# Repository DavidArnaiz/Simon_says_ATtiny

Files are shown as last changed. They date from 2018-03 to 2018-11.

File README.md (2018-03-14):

# Simon_says_ATtiny

Simon game on ATtiny45/85 microcontroller

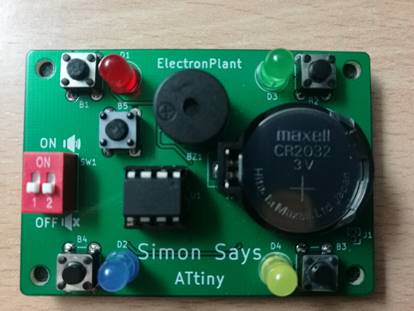
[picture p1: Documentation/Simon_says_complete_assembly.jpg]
Simon_says_ATtiny


Simon_says_ATtiny is a simple project implementing the Simon game on a PCB controlled from a ATtiny45/85. 
The ATtiny is programed from the Arduino IDE.

Repository contents:
--------------------

 +) Documentation: BOM file, Technical specification, drawings...
 
 +) Hardware: Kicad project files, schematic in PDF and Gerber files
 
 +) Firmware: Arduino code.

Game description:
-----------------
Simon (Simon says) game is an electronic game created by Ralph H. Baer and Howard J. Morrison and it has been available since 1970. The game has four lights (typically red, green, yellow and blue) and four buttons. Each light has one button and one sound, generally a tone, linked to it. The game has two main phases:

  +) Sequence display: during this phase “Simon”, the game, will show the sequence you have to memorize. The sequence is shown by turning the lights one at a time until the sequence is completed. Throughout this phase the corresponding tones linked to the lights will also be played to serve as a memory aid.
  
  +) Copying phase: in this phase the player has to copy the sequence in the same order as displayed previously. To copy the sequence the player has to press the corresponding button linked to the light or tone it needs to copy. If there is a mistake while completing the sequence the game will end at that point.
  
These two sequences are repeated over and over increasing the sequence length until either the player louses or the maximum length sequence is reached. The game starts with a sequence of only length one and its length is increased adding one extra step to the current sequence.

Acknowledgments
----------------

For this project to work I'm using the Arduino core created by SpenceKonde:

https://github.com/SpenceKonde/ATTinyCore

Arduino community (Arduino IDE available there):

https://www.arduino.cc/

[The rest of attributions will be on the technical specification document]

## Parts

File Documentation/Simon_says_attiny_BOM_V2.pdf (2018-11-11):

## Simon Says ATtiny BOM

Project Name: | Simon Says Attiny
Designer: | ElectronPlant
Revision: | Rev 1
Date Issue: | 26/01/2018
Reference | Value | Installed | Comment | Quantity

Farnell
code | Digikey code
ATTINY45-20PU U1 | Yes | Attiny45/85 | 1 1288352 | ATTINY45-20PU-ND
NA DIP8 socket | Yes | DIP 8 Socket 1 2668408 | | AE9986-ND
BZ1 Buzzer | Yes | 16 ohm 2k buzzer 1 | 1191946 | 433-1020-ND
SW1 SW_DIP_x02 | Yes | dip swtich 2 bits 1 9472126 | | CT2062ST-ND
J1 AA_Battery | No | | 0
J2 Cell_Battery | Yes | 3V battery holder 20mm | 1 1339839 | | BS-7-ND
B1, B2, B3, B4, B5 SW_Push | Yes | 6mm push botton | 5 | 1960936 | 450-1650-ND
D1 RED_LED | Yes | 5 mm LED (diffuse light) | 1 1581135 | | 754-1264-ND
D3 GREEN_LED | Yes | 5 mm LED (diffuse light) | 1 | 1581138 | 67-1099-ND
D4 YELLOW_LED | Yes | 5 mm LED (diffuse light) | 1 | 1581219 | 754-1284-ND
D2 BLUE_LED | Yes | 5 mm LED (diffuse light) /ORANGE | 1 | 1581141 | 732-5015-ND
C1 22nF | No | SMD 0805 | 1 | 8820104 | 490-1628-2-ND
C2 0.1uF | Yes | SMD 0805 | 1 | 1759143 | 399-1168-1-ND
R1, R5, R6, R7, R9 10k | Yes | SMD 0805 1% tolerance | 5 | 2502671 | 311-10.0KCRCT-ND
R2 20k | Yes | SMD 0805 1% tolerance | 1 | 2073683 | RNCP0805FTD20K0CT-ND
R3 30k | Yes | SMD 0805 1% tolerance | 1 | 2502713 | 311-30.0KCRCT-ND
R4 51k | Yes | SMD 0805 | 1 | 2671056 | 311-51.0KCRCT-ND
R8 100R | Yes | SMD 0805 | 1 | 9333703 | P100DACT-ND
R10, R11, R12, R13 47R | Yes | SMD 0805 | 4 | 2502729 | RHM47KCT-ND

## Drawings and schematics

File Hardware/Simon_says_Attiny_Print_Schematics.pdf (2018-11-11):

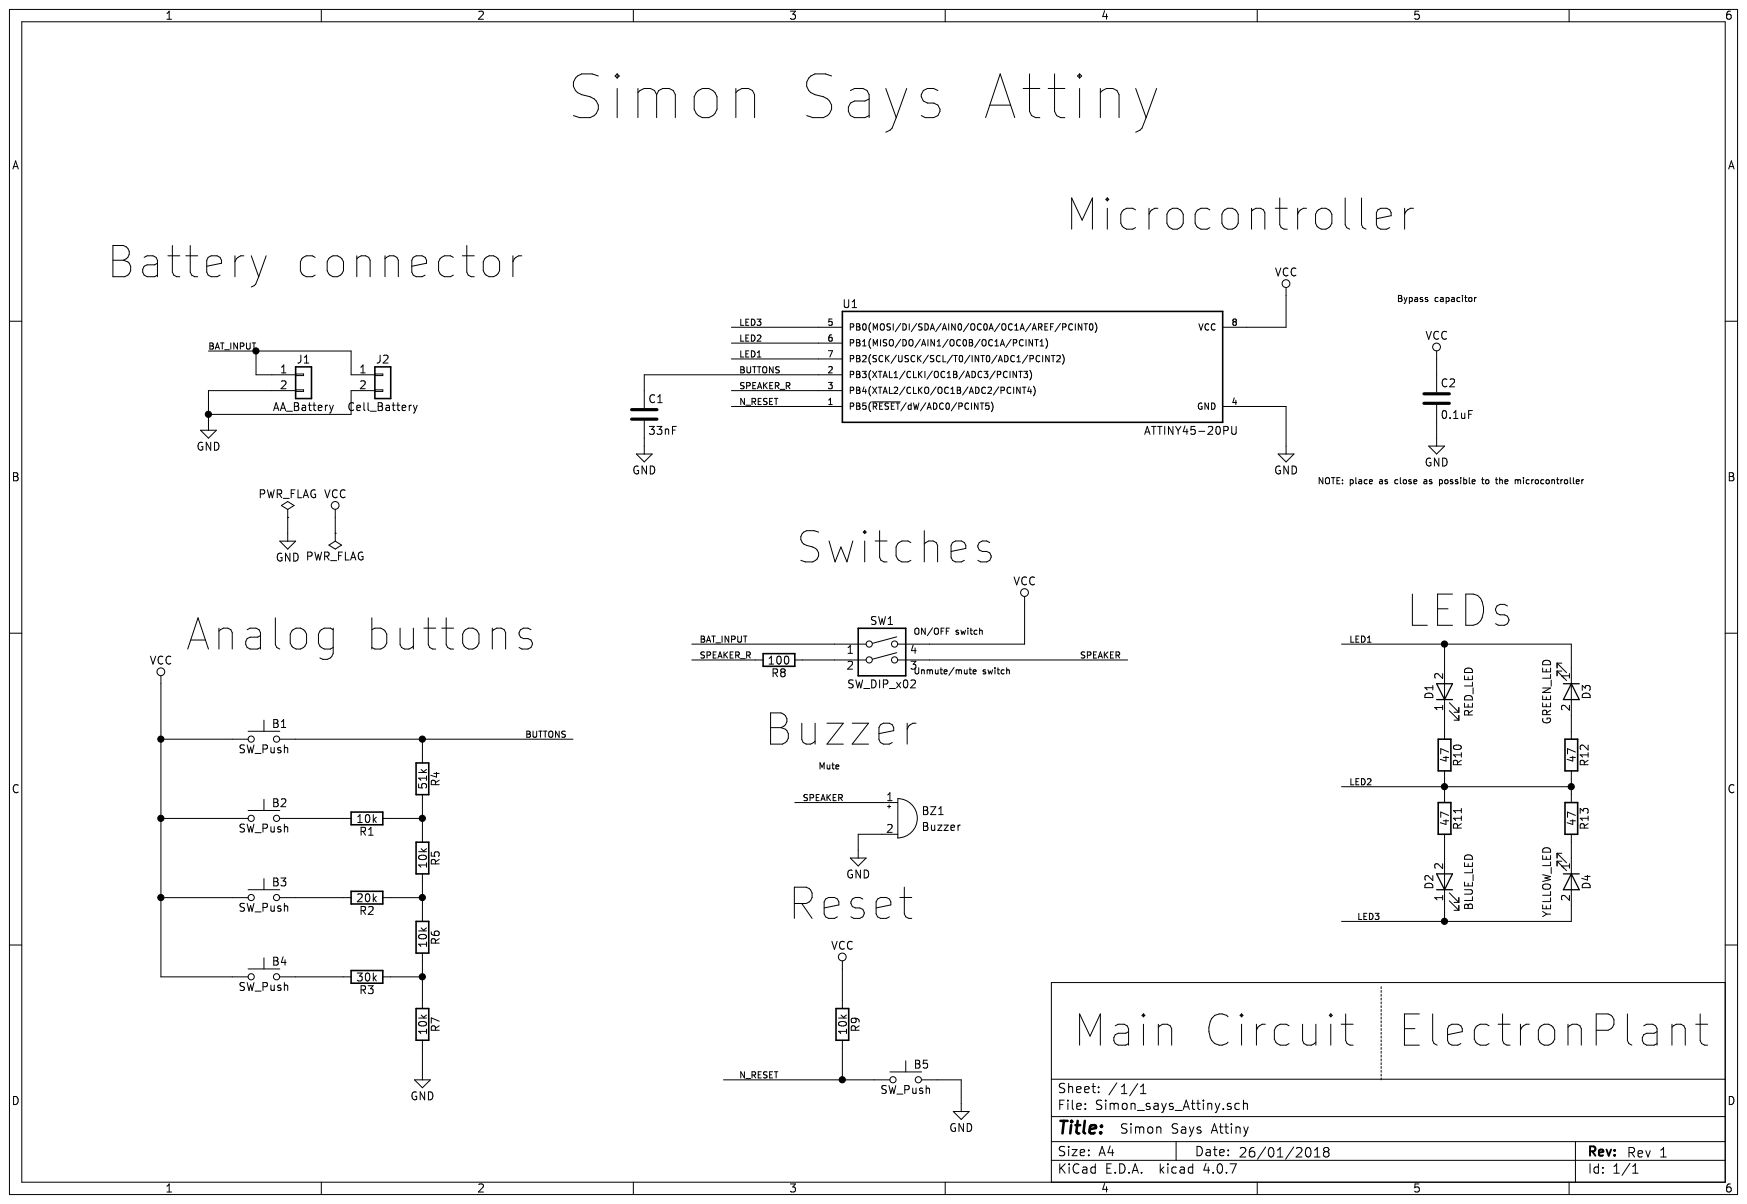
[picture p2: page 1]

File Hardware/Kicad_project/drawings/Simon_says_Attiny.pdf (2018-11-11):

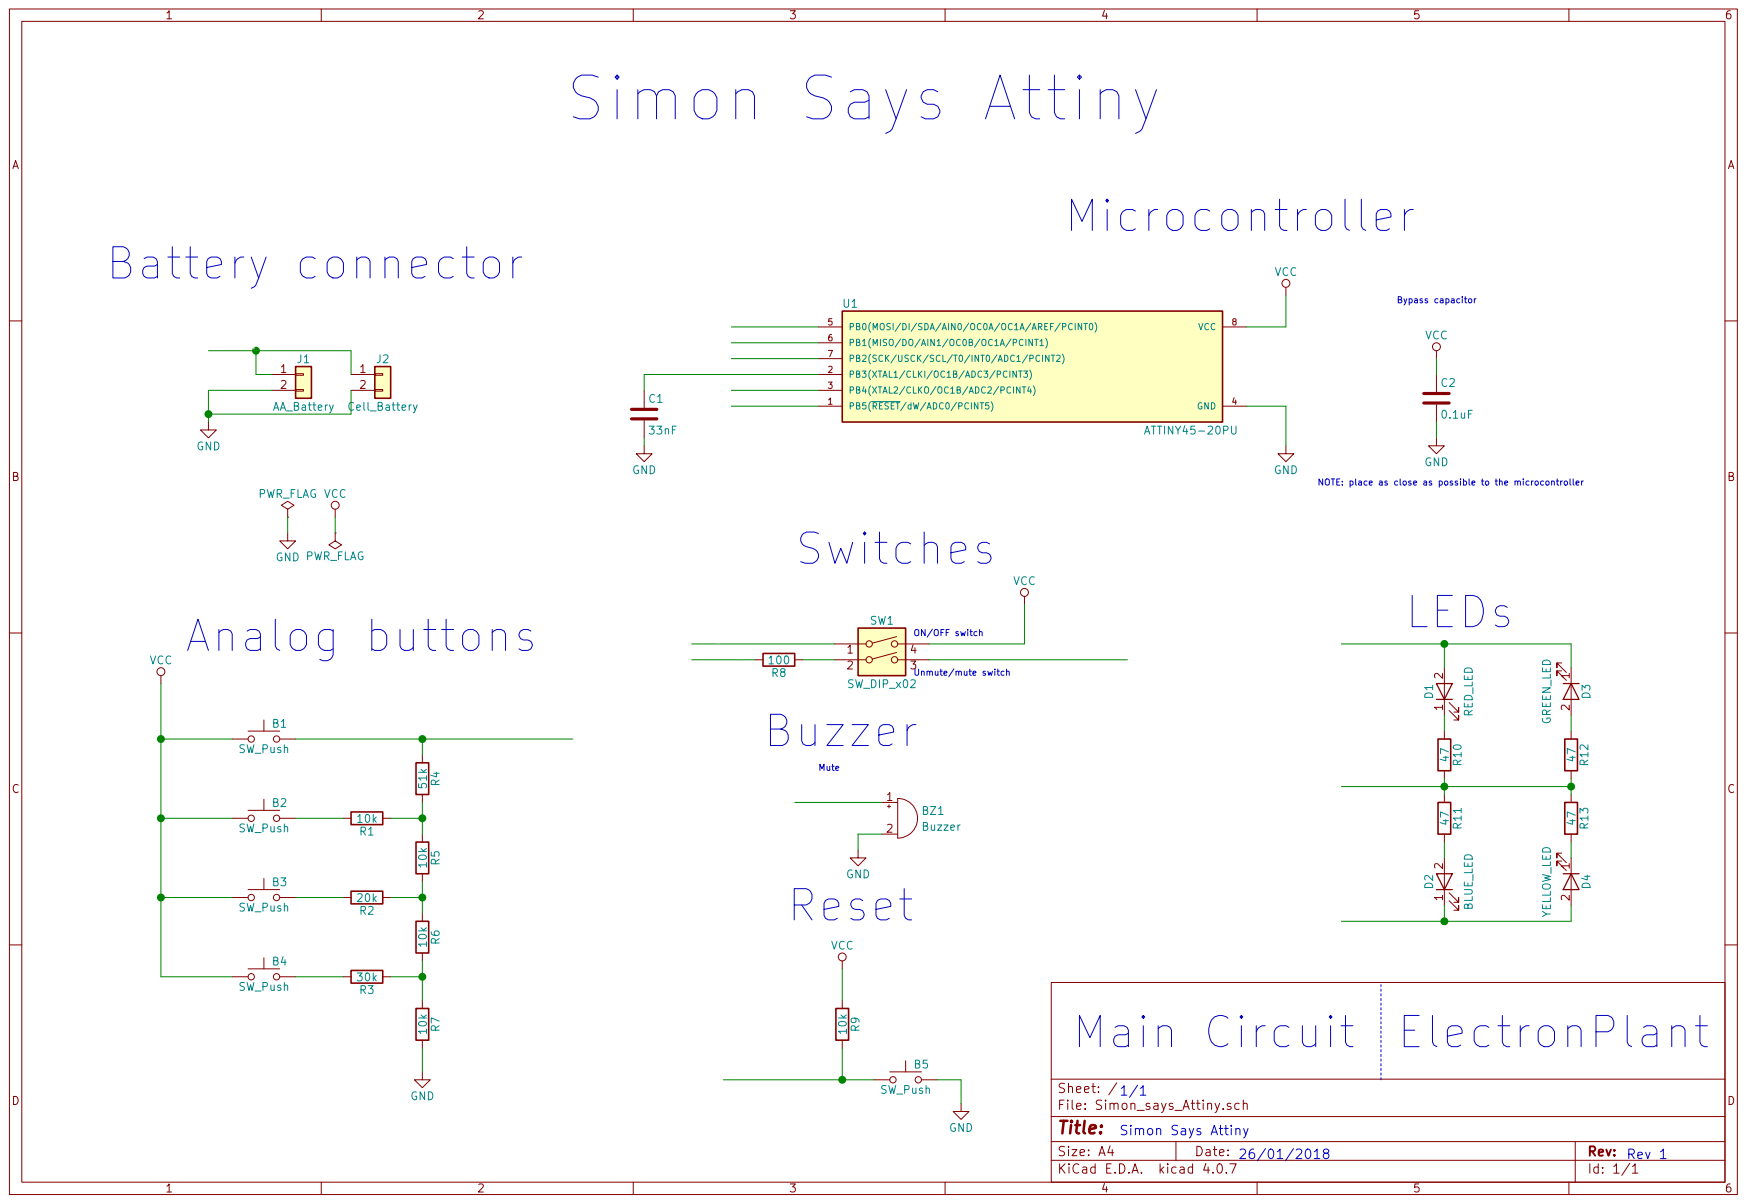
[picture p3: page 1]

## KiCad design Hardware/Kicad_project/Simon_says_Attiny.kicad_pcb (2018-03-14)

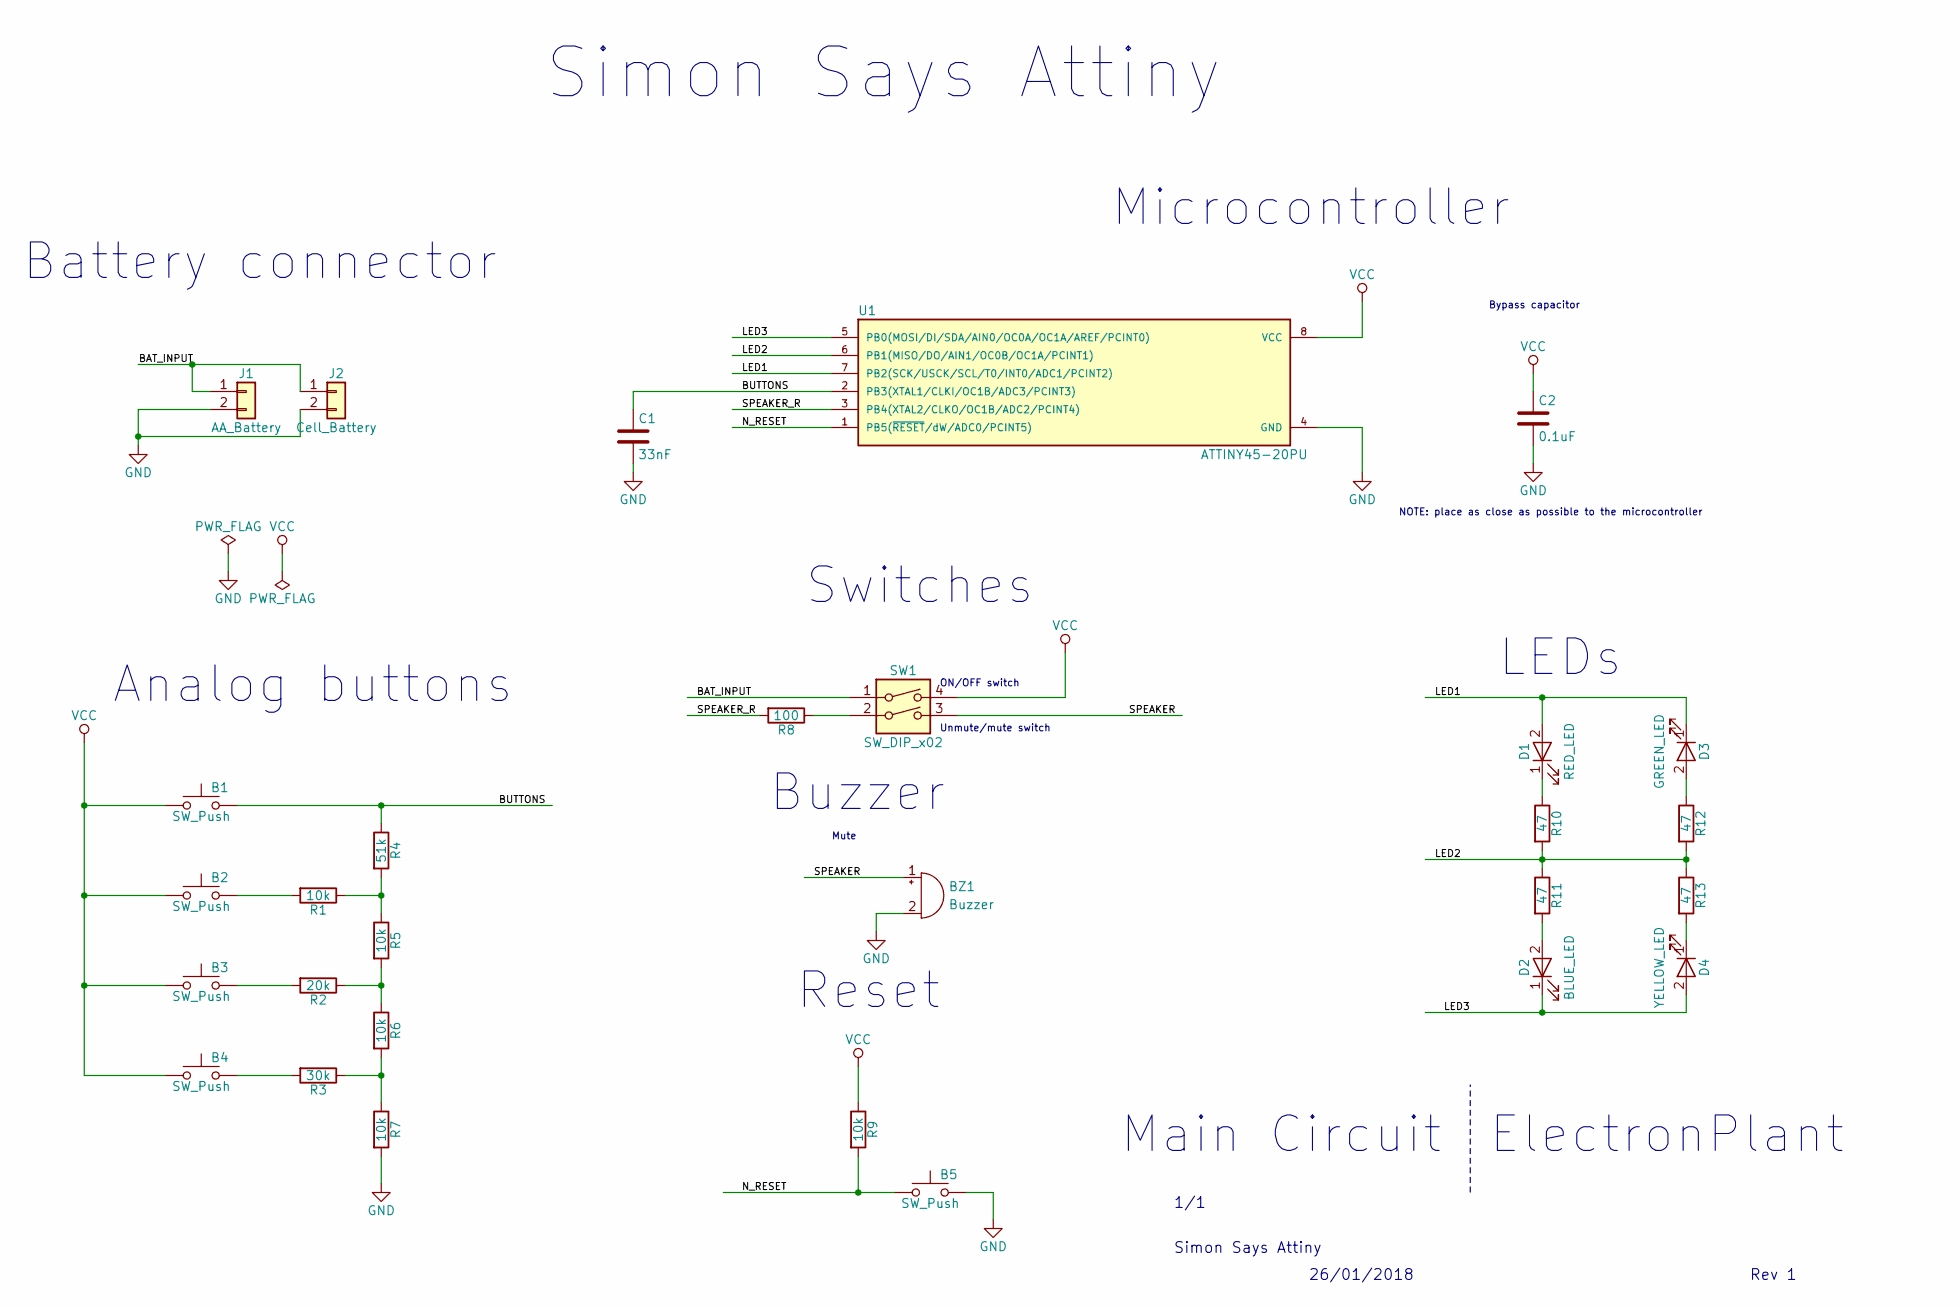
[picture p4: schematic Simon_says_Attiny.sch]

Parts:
B1, B2, B3, B4, B5: SW_Push; SW_PUSH_6mm
BZ1: Buzzer; Buzzer_12x9.5RM7.6
C1: 33nF; C_0805_HandSoldering
C2: 0.1uF; C_0805_HandSoldering
D1: RED_LED; LED_D5.0mm
D2: BLUE_LED; LED_D5.0mm
D3: GREEN_LED; LED_D5.0mm
D4: YELLOW_LED; LED_D5.0mm
J1: AA_Battery; Pin_Header_Straight_1x02_Pitch1.27mm
J2: Cell_Battery; Keystone_103_1x20mm-CoinCell
R1, R5, R6, R7, R9: 10k; R_0805_HandSoldering
R2: 20k; R_0805_HandSoldering
R3: 30k; R_0805_HandSoldering
R4: 51k; R_0805_HandSoldering
R8: 100; R_0805_HandSoldering
R10, R11, R12, R13: 47; R_0805_HandSoldering
SW1: SW_DIP_x02; SW_DIP_x2_W7.62mm_Slide
U1: ATTINY45-20PU; DIP-8_W7.62mm

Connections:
/BAT_INPUT: J1.1, J2.1, SW1.1
/BUTTONS: B1.2, C1.1, R4.1, U1.2 (PB3(XTAL1/CLKI/OC1B/ADC3/PCINT3))
/LED1: D1.2 (A), D3.1 (K), U1.7 (PB2(SCK/USCK/SCL/T0/INT0/ADC1/PCINT2))
/LED2: R10.2, R11.1, R12.2, R13.1, U1.6 (PB1(MISO/DO/AIN1/OC0B/OC1A/PCINT1))
/LED3: D2.1 (K), D4.2 (A), U1.5 (PB0(MOSI/DI/SDA/AIN0/OC0A/OC1A/AREF/PCI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)
/N_RESET: B5.1, R9.2, U1.1 (PB5(~RESET~/dW/ADC0/PCINT5))
/SPEAKER: BZ1.1 (-), SW1.3
/SPEAKER_R: R8.2, U1.3 (PB4(XTAL2/CLKO/OC1B/ADC2/PCINT4))
GND: B5.2, BZ1.2 (+), C1.2, C2.2, J1.2, J2.2, R7.2, U1.4 (GND)
unnamed: B2.2, R1.2
unnamed: B3.2, R2.2
unnamed: B4.2, R3.2
unnamed: D1.1 (K), R10.1
unnamed: D2.2 (A), R11.2
unnamed: D3.2 (A), R12.1
unnamed: D4.1 (K), R13.2
unnamed: R1.1, R4.2, R5.1
unnamed: R2.1, R5.2, R6.1
unnamed: R3.1, R6.2, R7.1
unnamed: R8.1, SW1.2
VCC: B1.1, B2.1, B3.1, B4.1, C2.1, R9.1, SW1.4, U1.8 (VCC)

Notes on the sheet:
Simon Says Attiny
26/01/2018
Rev 1
1/1
ElectronPlant
Main Circuit
Microcontroller
Bypass capacitor
NOTE: place as close as possible to the microcontroller
Buzzer
Analog buttons
Reset
LEDs
Battery connector
ON/OFF switch
Mute
Simon Says Attiny
Unmute/mute switch
Switches

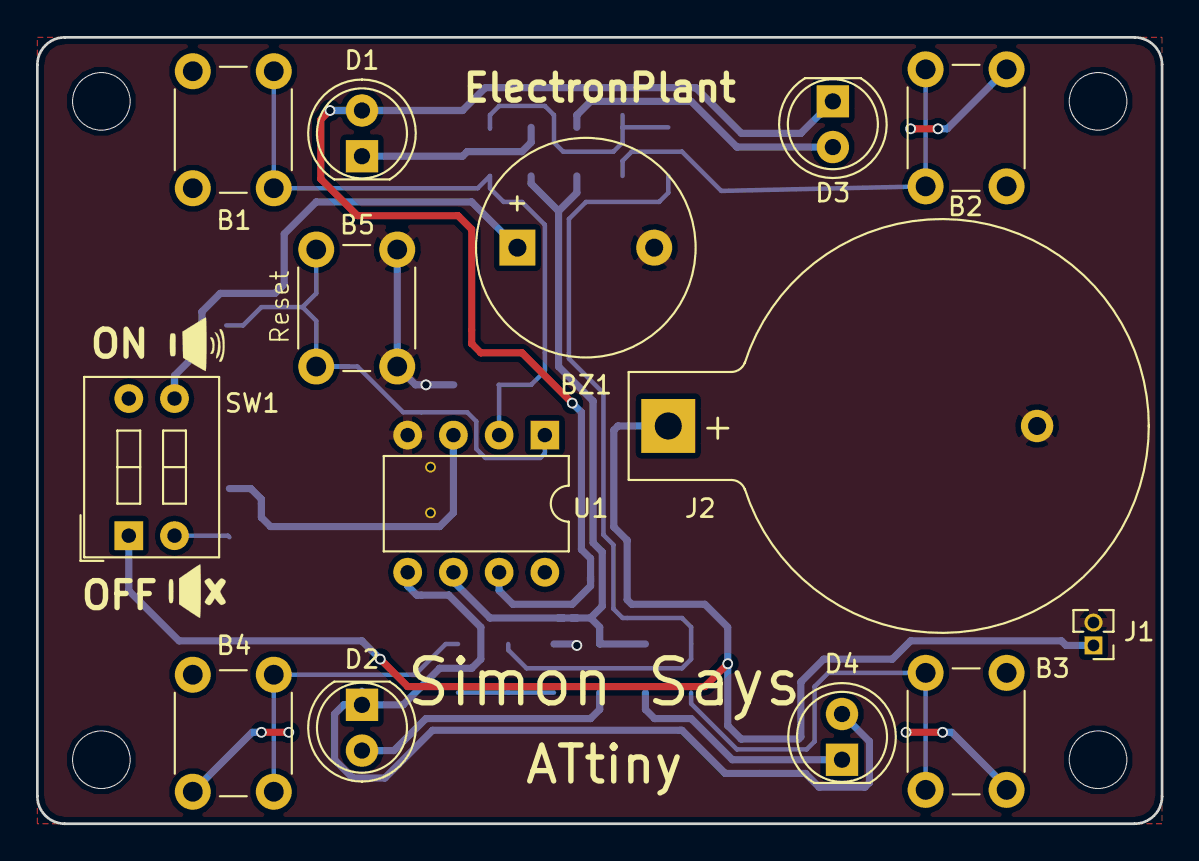
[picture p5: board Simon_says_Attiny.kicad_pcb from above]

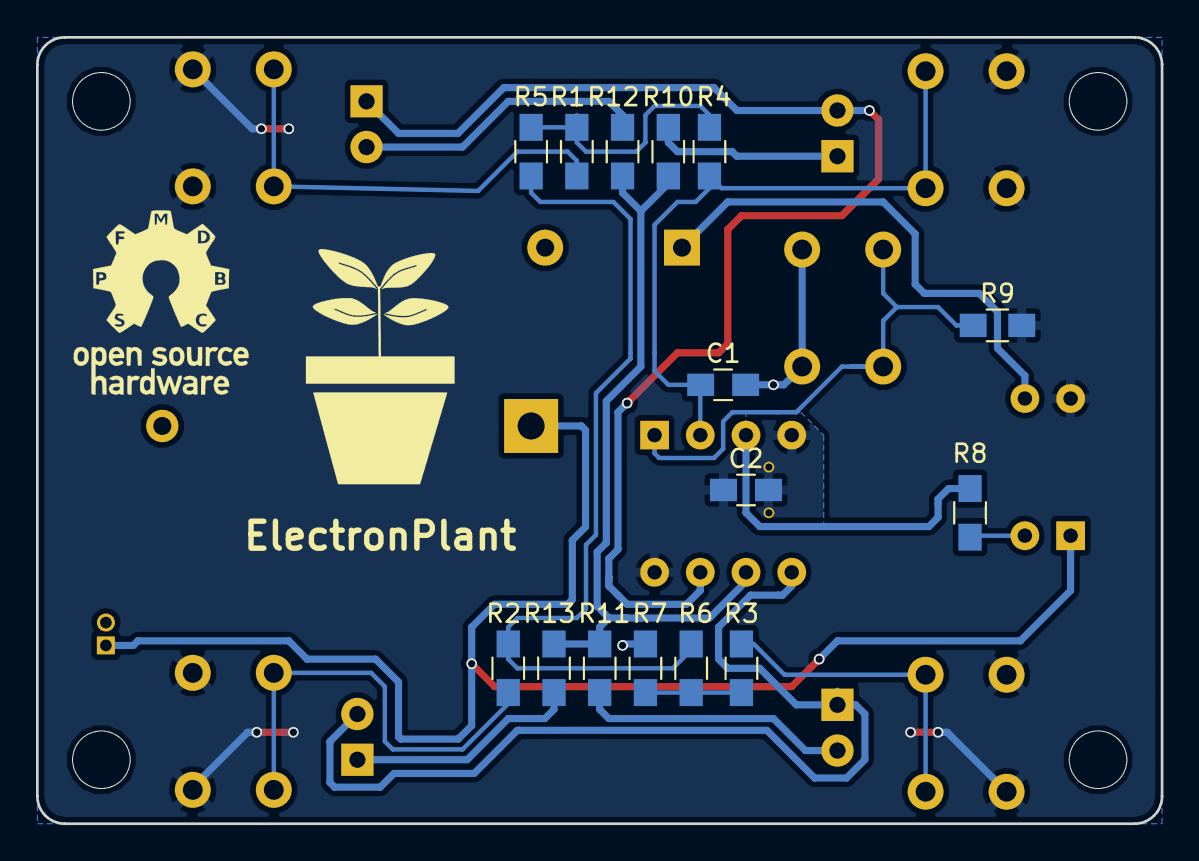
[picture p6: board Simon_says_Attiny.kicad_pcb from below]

Board: 2 copper layers, 62.5 x 43.7 mm, 29 parts (15 on the bottom side), 21 nets.

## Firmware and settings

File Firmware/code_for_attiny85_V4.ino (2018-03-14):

/*
                      *******************
                      *Simon says ATtiny*
                      *******************

   Written by: ElectronPlant
   Github: https://github.com/ElectronPlant/Simon_says_ATtiny

   Released under the Attribution-ShareAlike 4.0 International (CC BY-SA 4.0)
   license (https://creativecommons.org/licenses/by-sa/4.0/)
 ________________________________________________
   Simon says code for ATtiny_85

   V3:
    -) Analog thresholds corrected.
    -) LED glitches eliminated.
    -) Speaker support added. New core installed:
       https://github.com/SpenceKonde/ATTinyCore
   V4:
    -) Analog reading averaging
*/

// Pin definition
// LED pins
/*        ::Note::
 *  LED pins shouldn't be changed. 
 *  Because the way they are connected if pins aren't 
 *  changed all at the same time glitches occur and therefore the LEDs 
 *  will blink for a fraction of a second. To correct this the function 
 *  "digitalWrite()" function was replaced by "PORTB = B00000XXX". 
 *  If any change is done on the LEDs pins this should be adjusted. More 
 *  information can be read at:
 *  http://playground.arduino.cc/Learning/PortManipulation *  
 */
#define LED_1 2
#define LED_2 1
#define LED_3 0
// Buttons pin
#define ANALOG_PIN 3  // This is the analog read pin (pin 3)
// Speaker pin
/*        ::Note::
 *  In the core notes is advised to use the "tone()" function on pin 4.  
 *  https://github.com/SpenceKonde/ATTinyCore
 */
#define SPEAKER 4

// Tones
#define RED 200
#define YELLOW 400
#define GREEN 600
#define BLUE 800
#define DURATION 100

// Analog thresholds
#define BUTTON1_THRES 895  // Button 1
#define BUTTON2_THRES 636  // Button 2
#define BUTTON3_THRES 383  // Button 3
#define BUTTON4_THRES 150  // Button 4

/* Sequence length. It can be increased but if it is increased too much 
 * it may cause errors during compilation:

  +Global variables use 226 bytes (88%) of dynamic memory, leaving 
  30 bytes for local variables. Maximum is 256 bytes.
   Low memory available, stability problems may occur
   or
  +Not enough memory; see http://www.arduino.cc/en/Guide/Troubleshooting#size 
  for tips on reducing your footprint.
   Error compiling for board ATtiny25/45/85.
 */
#define MAX_LENGTH 20  // sequence reduced to have a winnable game (-_-)

// Variables
byte sequence[MAX_LENGTH];  // Array that stores the sequence
byte done = 0;  // Current level
int speed = 800;  // Delay time for the sequence display


// Functions

int getAnalogValue(byte pinNum){  // gets the averaged analog input
  /* To reduce the effects of noise in the measurement the final value will
   *  be averaged from 5 readings.
   *  The readings will be done with no delays to avoid having any effect if a
   *  button is pressed while getting the measurements(the capacitor will 
   *  help with this). This will take 500us to complete.
   */
   int value = 0;
   for(byte i = 0; i < 5; i++){  // Get the measurements and add them
    value += analogRead(pinNum);
   }
   value = value/5;  // Calculate the average
   return value;
}


byte readbutton() { // Checks what button is pressed
  /* The button pressed if coded the following way
      + 0 for no button pressed or error
      + 1 for button 1 --> Red
      + 2 for button 2 --> Green
      + 3 for button 3 --> Yellow
      + 4 for button 4 --> Blue
      Each button has a Threshold defined. To avoid debounce effects 
      in the button the buttons are read once, then it will wait for 
      50 ms and read again. Only if the two reading are the same the
      button will be considered as pressed.

  */
  byte button = 0;
  int analog = getAnalogValue(ANALOG_PIN);
  if (analog >= BUTTON1_THRES) {  // Button 1
    button = 1;
  } else if (analog >= BUTTON2_THRES) {  // Button 2
    button = 2;
  } else if (analog >= BUTTON3_THRES) {  // Button 3
    button = 3;
  } else if (analog >= BUTTON4_THRES) {  // Button 4
    button = 4;
  }
  if (button != 0) {  // Only wait if the button has been pressed.
    delay(50);
    analog = analogRead(ANALOG_PIN);
    if (analog >= BUTTON1_THRES) {  // Button 1
      if (button != 1) button = 0;
    } else if (analog >= BUTTON2_THRES) {  // Button 2
      if (button != 2) button = 0;
    } else if (analog >= BUTTON3_THRES) {  // Button 3
      if (button != 3) button = 0;
    } else if (analog >= BUTTON4_THRES) {  // Button 4
      if (button != 4) button = 0;
    }
  }
  return button;
}


void ledplay(byte k, boolean sound) { // lights the indicated LED and plays the tone associated to it
  switch (k) {
    case 1:  // Red
      PORTB = B00000100;
      if (sound) tone(SPEAKER, RED, DURATION);
      break;
    case 2:  // Green
      PORTB = B00000011;
      if (sound) tone(SPEAKER, GREEN, DURATION);
      break;
    case 3:  // Yellow
      PORTB = B00000001;
      if (sound) tone(SPEAKER, YELLOW, DURATION);
      break;
    case 4:  // Blue
      PORTB = B00000110;
      if (sound) tone(SPEAKER, BLUE, DURATION);
      break;
    default:  // Off
      PORTB = B00000000;
      break;
  }
}


void playsequence(byte* sec, byte len) { // Play the stored sequence
  for (byte i = 0; i < len; i++) {  // repeat for every element of the array
    delay(speed);
    ledplay(*(sec + i), true);  // Light the LED and play the sound linked to the current element
    delay(speed);
    // Turn off LEDs
    PORTB = B00000000;
  }
}

boolean checksequence(byte* sec, byte len) { // Check if the player copies the 
                                             // sequence (return true) or of not (return false).
  for (byte i = 0; i < len; i++) {  //repeat this for every element in the array
    unsigned long ttime = millis();  // sets the time to reset the game if no key is pressed
    // Wait for no button to be pressed
    while (readbutton() != 0) {
      delay(10);
      if (millis() - ttime > 30000) { // check if the reset time has passed
        PORTB = B00000000;
        return false;
      }
    }
    // Turn off LEDs
    PORTB = B00000000;
    byte k = 0;
    // wait for any pressed button
    while (k == 0) {
      k = readbutton();
      delay(10);
      if (millis() - ttime > 30000) {  // check if the reset time has passed
        PORTB = B00000000;
        return false;
      }
    }
    // Turn on LED
    ledplay(k, true);
    delay(50);
    // check if the button pressed is wrong
    if (k != *(sec + i)) {  // compares the button with the element of the array
      while (readbutton() != 0) {  // wait for button to be released
        delay(10);
      }
      // The button isn't correct
      tone(SPEAKER, 100, 500);
      for (byte j = 0; j < 50; j++){  // Turn all LEDs on
        PORTB = B00000010;
        delay(5);
        PORTB = B00000101;
        delay(5);
      }
      //delay(500);
      for (byte j = 0; j < len; j++){
        // PORTB = B00000000;  // turn LEDs off
        // tone(SPEAKER, 100, 50);
        tone(SPEAKER, 100, 50);
        PORTB = B00000000;
        delay (300);
        tone(SPEAKER, 300, 50);
        ledplay(*(sec + i), false);  // Turn the correct LED on
        delay(300);
      }
      PORTB = 00000000;
      return false;  // the button isn't correct :( game over
    }
  }
  // Sequence completed :)
  while (readbutton() != 0) {
    delay(10);
  }
  PORTB = B00000000;
  return true;
}


void intro() { // Play intro animation
  tone(SPEAKER, 700, 100);
  // Turn red on
  PORTB = B00000100;
  tone(SPEAKER, 300, 200);
  delay(500);
  // Turn green on
  tone(SPEAKER, 200, 100);
  PORTB = B00000011;
  delay(500);
  tone(SPEAKER, 400, 100);
  // Turn yellow on
  PORTB = B00000001;
  tone(SPEAKER, 100, 300);
  delay(500);
  // Turn blue on
  PORTB = B00000110;
  tone(SPEAKER, 700, 50);
  delay(500);
  // Turn all leds off
  PORTB = B00000000;
  tone(SPEAKER, 450, 200);
}


void lose() { // Play lose animation :(
  // Play game over sequence
  tone(SPEAKER, 100, 50);
  for (int i = 0; i < 8; i++) {
    // Turn on leds red and yellow
    PORTB = B00000101;
    tone(SPEAKER, 300, 50);
    delay(100);
    // Turn on leds 1 and 4
    PORTB = B00000010;
    delay(100);
    tone(SPEAKER, 100, 50);
  }
  // Turn off all LEDs
  PORTB = B00000000;
  noTone(SPEAKER);
}


void winSequence(){  // Play the wining sequence :D
  for (int j = 50; j < 1500; j+=5) {
    tone(SPEAKER, j, 10);
    if (j % 10 == 0) {
      PORTB = B00000101;
    } else {
      PORTB = B00000010;
    }
    delay(10);
  }
  for (int j = 1500; j > 50; j-=5) {
    tone(SPEAKER, j, 10);
    if (j % 10 == 0) {
      PORTB = B00000101;
    } else {
      PORTB = B00000010;
    }
    delay(10);
  }
  //PORTB = B00000000;
  delay(100);
  PORTB = B00000101;
  tone(SPEAKER, 800, 100);
  delay(300);
  tone(SPEAKER, 1000, 50);
  delay(150);
  PORTB = B00000010;
  tone(SPEAKER, 1400, 50);
  delay(200);
  tone(SPEAKER, 800, 100);
  delay(150);
  tone(SPEAKER, 1500, 100);
  PORTB = B00000101;
  delay(500);
  PORTB = B00000010;
  delay(500);
  PORTB = B00000000;
}


// Main code
void setup() {
  pinMode(LED_1, OUTPUT);
  pinMode(LED_2, OUTPUT);
  pinMode(LED_3, OUTPUT);
  pinMode(SPEAKER, OUTPUT);
  analogReference(DEFAULT);  // Sets Vcc as reference (not needed)

  // Play intro
  intro();
}

void loop() {
  // Start the game
  // Whait for any button to be pressed
  int key = 0;
  while (key == 0) {
    key = readbutton();
  }
  ledplay(key, true);  // Turn LED on
  while (readbutton() != 0) {  // Wait for the button to be released
  }
  PORTB = B00000000;  // Turn LEDs off
  randomSeed(millis());
  // Game loop
  while (true) {
    // Add one to the sequence
    done++;
    if (done < MAX_LENGTH) {
      sequence[done - 1] = random(1, 5);
      // Play sequence
      playsequence(sequence, done);
      // Check sequence
      if (!checksequence(sequence, done)) {  // Game over, reset the game
        lose();  // Play game over animation
        done = 0;
        speed = 800;
        break;
      }
      if (speed > 100) {  // // Increase the speed of the game (to a limit)
        speed -= speed / 4;  
      }
      delay(250);

    } else {  // Game completed, reset the game
      winSequence();  // play win animation
      done = 0;
      speed = 800;
      break;
    }
  }
}

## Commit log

2018-03-14 files added
    Code --> comment correction
    Harware files uploaded
    :)
    [Simon_says_Attiny.kicad_pcb, Simon_says_Attiny.sch]
2018-03-14 BOM added
    Added the BOM file
2018-03-14 BOM corrected
2018-11-11 BOM and Schematics corrected
    PDF files replaced by their new version
2018-11-11 Schematics correction
    The PDF didn't generate correctly :(
